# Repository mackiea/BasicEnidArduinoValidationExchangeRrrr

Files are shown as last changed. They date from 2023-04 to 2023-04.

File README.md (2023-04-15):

# BasicEnidArduinoValidationExchangeRrrr
An interface from the [NABU](https://nabu.ca/) via [ENID](https://github.com/mackiea/ExternalNabuInterfaceDevice) to the [Adafruit Boarduino](https://www.gravitech.us/usbboacokitv.html).

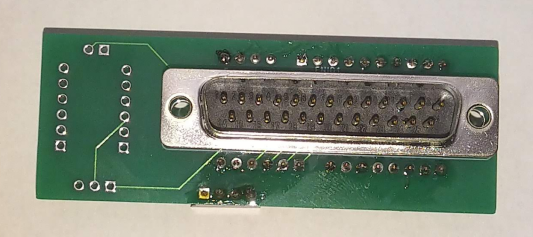
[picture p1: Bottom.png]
Bottom

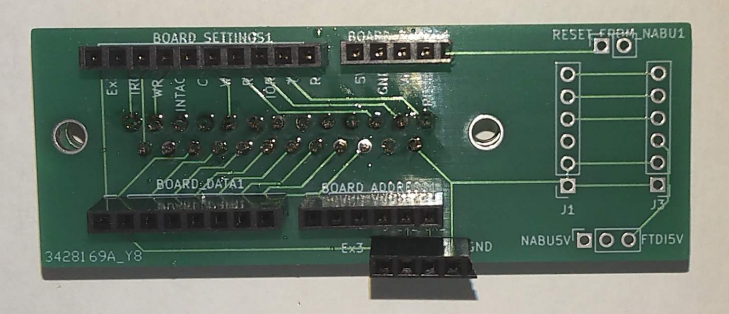
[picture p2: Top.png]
Top


# Why interface an Arduino to a NABU?
* Debugging using a serial interface. During graphical operations, it's not easy or desirable to spit out the value of the variable asdf123wtf onto the TV screen.
* Nailing down how the NABU's Option Card protocol works. The documentation I have doesn't go into detail about active lows, signal timing, and order. I want a microcontroller to read and log these signals.
* Prototyping functionality. Most of the option cards I'd like to add will probably involve a microcontroller. Arduino is as good as any!

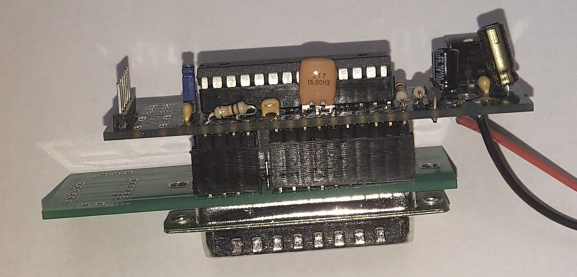
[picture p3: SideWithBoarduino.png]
Side with Boarduino

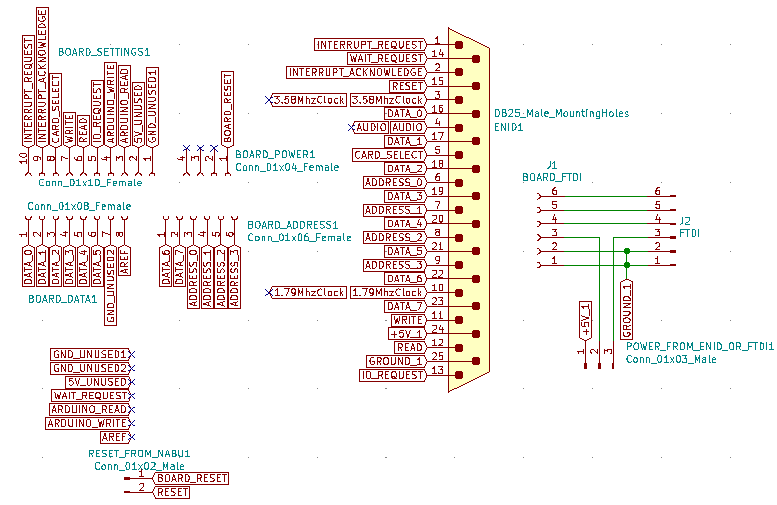
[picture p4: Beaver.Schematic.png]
schematic


## Why Boarduino? It's obsolete, deprecated, and old!
Because I still have a half-dozen Boarduino boards from an incomplete project from years back. I don't recommend using this unless you're in a similar situation. I will probably work on a standard ENID Arduino shield later on.
I *am* working on a Raspberry Pico interface -- [the INREPAIR](https://github.com/mackiea/InformationalNabuRemoteEnidPicoActiveInterfaceRelay).

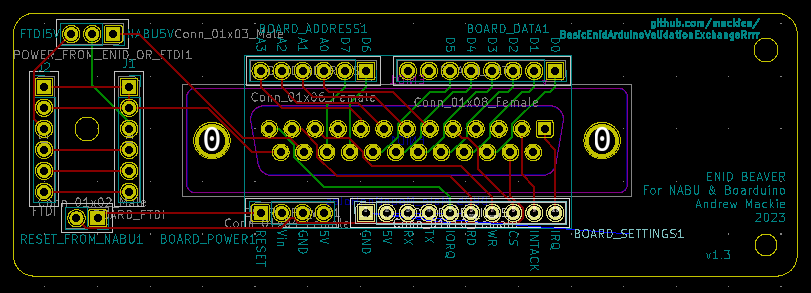
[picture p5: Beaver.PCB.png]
pcb


## Bill Of Materials?
|Part|
|----|
|[Male DB-25 connector](https://www.digikey.ca/en/products/detail/adam-tech/DB25-PT-1/9832353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)|
|2.54mm male & female headers|
|Boarduino|
|Banana|

Eat the banana, rethink your life choices, then slap this together!

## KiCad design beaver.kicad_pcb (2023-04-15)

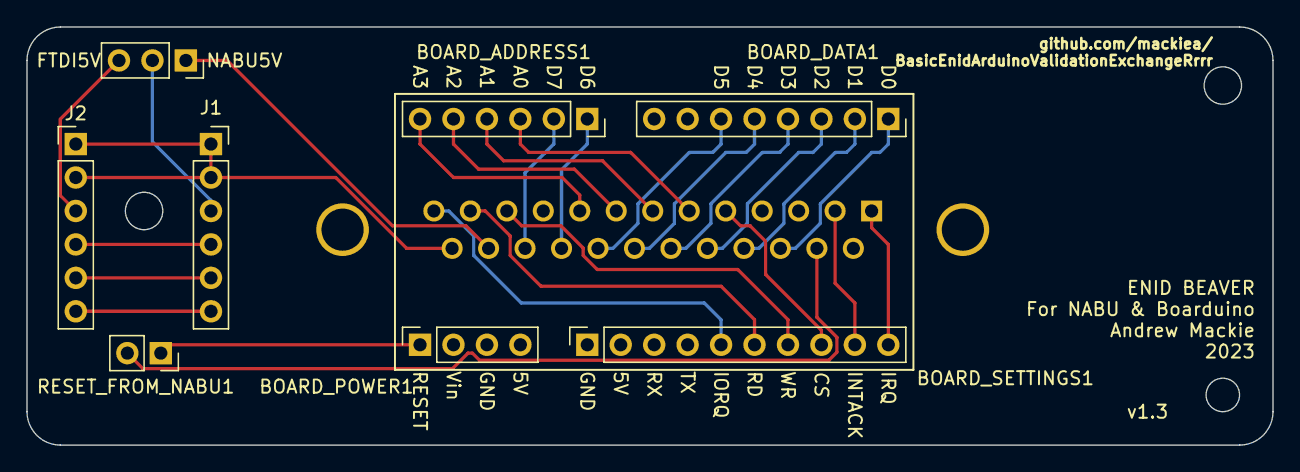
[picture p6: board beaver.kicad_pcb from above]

Board: 2 copper layers, 94.6 x 31.8 mm, 9 parts (1 on the bottom side), 27 nets.

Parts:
BOARD_ADDRESS1: Conn_01x06_Female; PinSocket_1x06_P2.54mm_Vertical
BOARD_DATA1: Conn_01x08_Female; PinSocket_1x08_P2.54mm_Vertical
BOARD_POWER1: Conn_01x04_Female; PinSocket_1x04_P2.54mm_Vertical
BOARD_SETTINGS1: Conn_01x10_Female; PinSocket_1x10_P2.54mm_Vertical
ENID1: DB25_Male_MountingHoles; DSUB-25_Male_Vertical_P2.77x2.84mm_MountingHoles
J1: BOARD_FTDI; PinSocket_1x06_P2.54mm_Vertical
J2: FTDI; PinHeader_1x06_P2.54mm_Vertical
POWER_FROM_ENID_OR_FTDI1: Conn_01x03_Male; PinSocket_1x03_P2.54mm_Vertical
RESET_FROM_NABU1: Conn_01x02_Male; PinSocket_1x02_P2.54mm_Vertical

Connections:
+5V_1: ENID1.24, POWER_FROM_ENID_OR_FTDI1.1
ADDRESS_0: BOARD_ADDRESS1.3, ENID1.6
ADDRESS_1: BOARD_ADDRESS1.4, ENID1.7
ADDRESS_2: BOARD_ADDRESS1.5, ENID1.8
ADDRESS_3: BOARD_ADDRESS1.6, ENID1.9
BOARD_RESET: BOARD_POWER1.1, RESET_FROM_NABU1.1
CARD_SELECT: BOARD_SETTINGS1.8, ENID1.5
DATA_0: BOARD_DATA1.1, ENID1.16
DATA_1: BOARD_DATA1.2, ENID1.17
DATA_2: BOARD_DATA1.3, ENID1.18
DATA_3: BOARD_DATA1.4, ENID1.19
DATA_4: BOARD_DATA1.5, ENID1.20
DATA_5: BOARD_DATA1.6, ENID1.21
DATA_6: BOARD_ADDRESS1.1, ENID1.22
DATA_7: BOARD_ADDRESS1.2, ENID1.23
GROUND_1: ENID1.25, J1.1, J1.2, J2.1, J2.2
INTERRUPT_ACKNOWLEDGE: BOARD_SETTINGS1.9, ENID1.2
INTERRUPT_REQUEST: BOARD_SETTINGS1.10, ENID1.1
IO_REQUEST: BOARD_SETTINGS1.5, ENID1.13
unnamed: J1.3, POWER_FROM_ENID_OR_FTDI1.2
unnamed: J1.4, J2.4
unnamed: J1.5, J2.5
unnamed: J1.6, J2.6
unnamed: J2.3, POWER_FROM_ENID_OR_FTDI1.3
READ: BOARD_SETTINGS1.6, ENID1.12
RESET: ENID1.15, RESET_FROM_NABU1.2
WRITE: BOARD_SETTINGS1.7, ENID1.11

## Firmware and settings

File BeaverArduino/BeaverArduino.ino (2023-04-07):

enum Nabu_pins {
  IO_REQUEST = 2,
  READ = 3,
  WRITE = 4,
  CARD_SELECT = 5,
  INTERRUPT_ACKNOWLEDGE = 6,
  WAIT_REQUEST=7,
  INTERRUPT_REQUEST = 8,

  EXTRA_2 = 9,

  DATA_0 = 10,
  DATA_1 = 11,
  DATA_2 = 12,
  DATA_3 = 13,
  DATA_4 = 14,
  DATA_5 = 15,
  DATA_6 = 16,
  DATA_7 = 17,

  ADDRESS_0 = 18,
  ADDRESS_1 = 19,
  ADDRESS_2 = 20,
  ADDRESS_3 = 21,

  EXTRA_1 = 22,
  EXTRA_0 = 23,

  SIZE = 24
};

#define DATA_PINS PINB

String pinName[SIZE] = {
  "IO_RD",
  "IO_WR"

  "IO_RQ",
  "RD",
  "WR",
  "CARD",
  "INT_ACK",
  "WAIT_RQ",
  "INT_RQ",

  "E2",

  "D0",
  "D1",
  "D2",
  "D3",
  "D4",
  "D5",
  "D6",
  "D7",

  "A0",
  "A1",
  "A2",
  "A3",

  "E1",
  "E0"
  };
boolean pinState[SIZE];

void reportState(String summary) {
  for (int pin = IO_REQUEST; pin < SIZE; pin++) {
    if(EXTRA_0 == pin || EXTRA_1 == pin || EXTRA_2 == pin) {
      continue; // Don't sense the floaty, unused pins.
    }
    Serial.print(pinState[pin] ? "1" : "0");
    if(INTERRUPT_REQUEST == pin) {
      Serial.print(" ");
    } else if(DATA_7 == pin) {
      Serial.print("(");
      Serial.print(String(DATA_PINS, HEX));
      Serial.print(") ");
    }
  }
  Serial.print(summary);
  Serial.println();
}

void setup() {
  Serial.begin(9600);
  while (!Serial) {
    delay(100);
  }

  Serial.println();
  Serial.println("Basic ENID Arduino Validation ExchangeRrr");
  Serial.println("-----------------------------------------");
  Serial.println("IRWCIWI     Data    Addr");
  Serial.println("RDRSARR 01234567Hex 0123");
  Serial.println("------- ----------- ----");

  for (int pin = IO_REQUEST; pin < SIZE; pin++) {
    pinMode(pin, INPUT);
    pinState[pin] = digitalRead(pin);
  }

  reportState("");
}

void loop() {
  String summary = "";
  boolean changed = false;
  for (int pin = IO_REQUEST; pin <= ADDRESS_3; pin++) {
    if(EXTRA_0 == pin || EXTRA_1 == pin || EXTRA_2 == pin) {
      continue; // Don't sense the floaty, unused pins.
    }
    boolean oldState = pinState[pin];
    pinState[pin] = digitalRead(pin);
    if(pinState[pin] != oldState) {
      changed = true;
      summary.concat(pinState[pin] ? " +" : " -");
      summary.concat(pinName[pin]);
    }
  }
  if(changed) {
    reportState(summary);
  }
}

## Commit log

2023-03-07 Added Kicad files.
    [beaver.kicad_pcb, beaver.sch]
2023-03-23 Added pics of printed boards
2023-04-07 Boarduino pinout was wrong for 4 pins. Will need to drop support for WAIT_REQUEST.
    [beaver.kicad_pcb, beaver.sch]
2023-04-07 Updated for Boarduino pinfix.
2023-04-07 Added first Arduino code.
2023-04-15 Corrected ENID's DB-25 orientation.
    [beaver.kicad_pcb, beaver.sch]
